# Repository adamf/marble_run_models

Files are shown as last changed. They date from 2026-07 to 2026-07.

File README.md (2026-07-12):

# marble_run_models



3D-printable models for translucent OEM marble runs (National Geographic
and similar). Parametric OpenSCAD source plus ready-to-slice STLs.

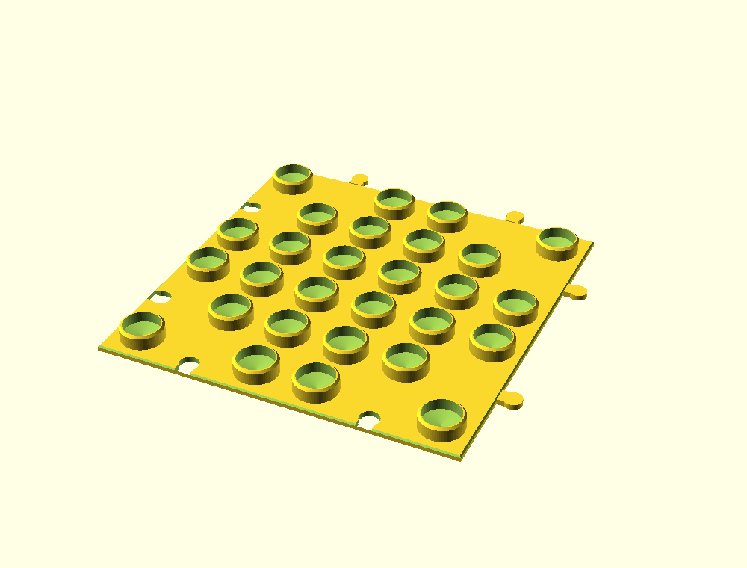
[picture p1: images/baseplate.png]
baseplate


## Base plate

A tileable base plate that gives marble-run stacks a stable footing. A
grid of hollow pegs plugs into the open (cup) end of the tubes the same
way the tubes' own male spigots plug into each other, so vertical columns
can't tip. Plates interlock edge-to-edge and the peg grid stays continuous
across the seams, so horizontal pieces can span two tiles.

| File | Description |
|---|---|
| `src/marble_run_baseplate.scad` | Parametric source (edit this) |
| `stl/marble_run_baseplate_5x5.stl` | 5×5 tile, 162×162×11mm |
| `stl/marble_run_calibration.stl` | Fit tester — **print this first** |

### Calibrate before printing tiles

Peg diameter depends on your exact tubes and can't be eyeballed. Print the
calibration strip (test pegs 24.0–27.0mm, labeled), push a real tube's cup
end onto each, and pick the snug one. Set `peg_od` to that value in the
`.scad`, re-export, then print tiles.

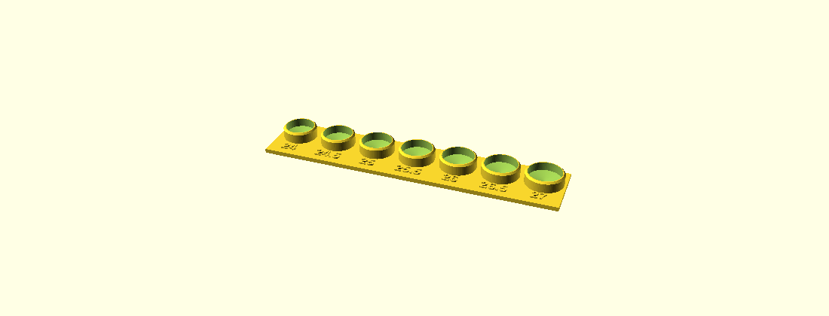
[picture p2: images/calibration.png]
calibration


### Print settings (Bambu)

Prints flat, pegs up, **no supports**.

- Material: PLA (easy) or PETG (tougher, better snap)
- Layer height: 0.2mm · Walls: 3–4 · Infill: 15–20%
- Brim: 5mm to prevent corner lift

### Key parameters

| Parameter | Purpose |
|---|---|
| `peg_od` | Peg diameter — the fit into your tubes (calibrate) |
| `pitch` | Grid spacing — match your set's module (default 30mm) |
| `grid_x`, `grid_y` | Pegs per tile |
| `peg_h` | Peg height / grip depth |
| `tab_tol` | Tightness of the plate-to-plate joint |

## Always-current models (CI)

A GitHub Actions workflow (`.github/workflows/build.yml`) re-renders the
STLs from the parametric source on every push that touches `src/`, then
commits the fresh models back into `stl/` and refreshes the preview images.
So the workflow is:

1. Edit a parameter in `src/marble_run_baseplate.scad` (e.g. `peg_od`
   after calibrating, or `grid_x`/`pitch`).
2. Commit and push.
3. A minute later, `stl/` holds the updated, ready-to-slice file — pulled
   straight into Bambu Studio, sliced in one click, sent to the printer.

The STLs are also attached to each run as downloadable **artifacts**
(Actions tab → latest run → *print-ready-stls*).

Run the same render locally any time with `./build.sh` (needs OpenSCAD).

> Note: replace `USERNAME` in the badge URL above with your GitHub handle.

## License

MIT — see [LICENSE](LICENSE). (Swap for CC-BY or remove if you'd rather.)

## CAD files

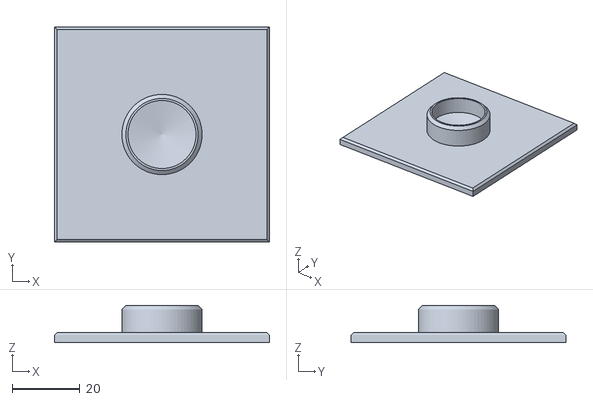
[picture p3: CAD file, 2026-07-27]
stl/marble_run_single_peg.stl
63.5 x 63.5 x 11.0

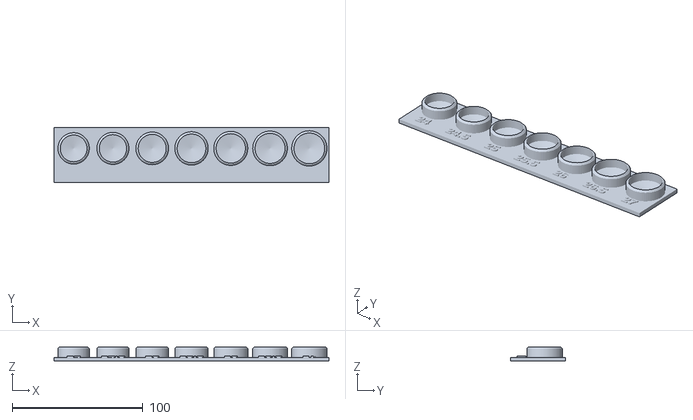
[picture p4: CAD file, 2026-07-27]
stl/marble_run_calibration.stl
210.0 x 42.0 x 11.0

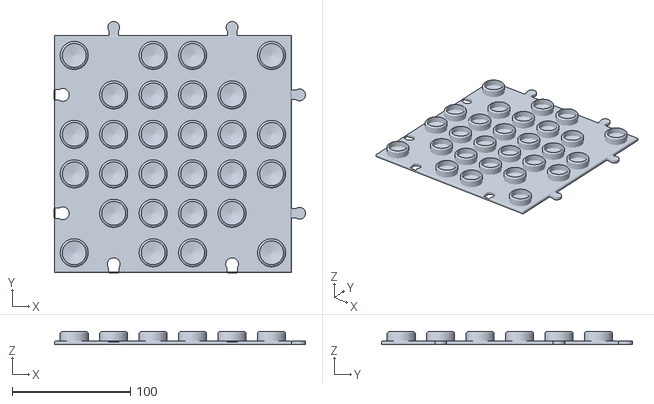
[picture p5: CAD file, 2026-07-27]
stl/marble_run_baseplate_6x6.stl
212.0 x 212.0 x 11.0

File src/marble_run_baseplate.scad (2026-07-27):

// =====================================================================
//  Marble-Run Base Plate  -  parametric, tileable, print-in-place
//  For National Geographic (and most translucent OEM) marble runs
//  Author: generated for Adam
//
//  HOW IT WORKS
//  ------------
//  A flat plate carries a grid of hollow pegs. Each peg is sized to
//  plug INTO the female (open) end of a marble-run tube, the same way
//  the tubes' own male spigots plug into each other. Stand a tube on a
//  peg and it can't tip. Pegs sit on a square grid whose pitch you set
//  to your set's module length, so horizontal pieces span whole grid
//  units. Plates interlock with jigsaw tabs so you can tile a big field.
//
//  >>> YOU MUST CALIBRATE peg_od TO YOUR TUBES <<<
//  Print marble_run_calibration.stl first (PART="calibration"),
//  push a real tube onto each test peg, pick the snuggest, and set
//  peg_od to that number below. Then print the tiles.
// =====================================================================

PART = "tile";          // "tile", "calibration", or "single"

// ---------- GRID ----------
grid_x       = 6;       // pegs across
grid_y       = 6;       // pegs deep
span_mod     = 100;     // measured span/ramp foot-to-foot center-to-center
subs_per_span = 3;      // pegs the span spans (feet land on pegs
                        //     subs_per_span cells apart, with subs-1
                        //     intermediate support pegs sitting under the
                        //     span body). Denser = more column-support
                        //     pegs. Limit: pitch > peg_od (no overlap), so
                        //     subs_per_span < span_mod/peg_od ~= 4.2, i.e.
                        //     max 4 (but 4 leaves only ~1mm gap between
                        //     peg edges - risky to print). 3 is comfy.
pitch        = span_mod / subs_per_span;
                        // == 100/3 = 33.333mm. Grid continuity (pegs at
                        // pitch/2 from every edge) means a span also fits
                        // across a seam: A's last peg sits pitch/2 from
                        // the seam, then N-1 intermediate pegs on B, then
                        // B's N-th peg lands 100mm from A_last.

// ---------- PEG (the bit that plugs into a tube) ----------
peg_od       = 23.7;    // <-- CALIBRATED for user's Bambu + Nat-Geo tubes:
                        //     firm/snug fit. Progression: 25.4 -> 24.0 ->
                        //     23.9 -> 23.8 -> 23.7 as the user dialed in a
                        //     slightly easier on/off.
                        //     Outer dia of peg = female-socket ID of your
                        //     tubes minus a snug clearance.
peg_wall     = 1.8;     // peg wall thickness (hollow peg flexes = grip)
peg_h        = 8;       // how far the peg sticks up
peg_top_cham = 1.2;     // lead-in chamfer at peg tip (easier to seat)
peg_flare_h  = 2.0;     // internal flare at the peg's base: the bore
                        //     tapers from fully closed at the underside up
                        //     to the nominal bore radius over this height,
                        //     then continues straight to the top. The wall
                        //     is thick at the base for strength, and the
                        //     outer stays flat at peg_od so tube feet seat
                        //     flush against the plate (no external lip).

// ---------- BASE ----------
base_th      = 3.0;     // plate thickness
edge_cham    = 0.8;     // top-perimeter chamfer (nicer to handle)

// ---------- TILE-TO-TILE CONNECTORS (jigsaw) ----------
connectors_on   = true;
conn_cells      = [1, 4];  // which edge grid-cells become connectors
                           // (0-indexed). Those edge pegs are omitted to
                           // make room. [1,4] = 2 per edge on a 6-wide,
                           // symmetric and clear of the corners.
tab_reach   = 12;       // how far a tab sticks out
tab_neck_w  = 8;        // neck width
tab_head_d  = 10;       // head diameter (>neck = it catches). Kept only
                        //   modestly larger so tiles PRESS together with
                        //   PLA's natural edge flex instead of needing a
                        //   hard snap that could crack.
tab_tol     = 0.40;     // clearance in the socket. Bigger = looser.
                        //   Too stiff to press together? raise to 0.6.
                        //   Falls apart? lower to 0.25.

// ---------- quality ----------
$fn = 64;

// ================= derived =================
plate_w = grid_x * pitch;   // physical footprint = N*pitch  -> grid stays
plate_d = grid_y * pitch;   // continuous across tiles (border = pitch/2)
eps = 0.01;

// ================= modules =================

// one hollow peg centered at origin, base sitting on z=0
module peg() {
    r  = peg_od/2;
    ri = r - peg_wall;
    // straight outer shaft (no external skirt) + tapered internal bore.
    difference() {
        union() {
            cylinder(h=peg_h - peg_top_cham, r=r);
            translate([0,0,peg_h - peg_top_cham])
                cylinder(h=peg_top_cham, r1=r, r2=r-peg_top_cham);
        }
        // bore: closed at the underside (r=0) tapering out to ri over
        // peg_flare_h -> reinforced base without any outer bump; then
        // straight ri up through and out the top.
        union() {
            cylinder(h=peg_flare_h, r1=0, r2=ri);
            translate([0,0,peg_flare_h - eps])
                cylinder(h=peg_h+1, r=ri);
        }
    }
}

// 2D jigsaw profile, protruding along +Y from the seam line y=0
module jigsaw2d(reach, neck_w, head_d, grow=0) {
    hr = head_d/2 + grow;
    nw = neck_w + 2*grow;
    hull_y = reach - head_d/2;      // head center
    union() {
        // neck
        translate([0,(hull_y)/2])
            square([nw, hull_y + eps], center=true);
        // head
        translate([0, hull_y]) circle(r=hr);
    }
}

// a connector TAB (adds material), seam at y=0, sticks toward +Y
module tab3d() {
    linear_extrude(base_th) jigsaw2d(tab_reach, tab_neck_w, tab_head_d, 0);
}
// a connector SOCKET (removes material), seam at y=0, opens toward -Y
module socket3d() {
    // mirror of the tab, grown by tolerance, pushed a hair past the seam
    translate([0,eps,-eps])
        linear_extrude(base_th+2*eps)
            jigsaw2d(tab_reach, tab_neck_w, tab_head_d, tab_tol);
}

// is edge-cell index k one of the connector cells?
function is_conn(k) = connectors_on &&
    len(search(k, conn_cells)) > 0;

// ================= the tile =================
module tile() {
    difference() {
        union() {
            // ---- base slab with chamfered top perimeter ----
            difference() {
                cube([plate_w, plate_d, base_th]);
                // chamfer top edges
                if (edge_cham > 0)
                    perimeter_chamfer();
            }

            // ---- pegs (skip edge cells that host a connector) ----
            for (i=[0:grid_x-1], j=[0:grid_y-1]) {
                on_left   = (i==0);
                on_right  = (i==grid_x-1);
                on_front  = (j==0);
                on_back   = (j==grid_y-1);
                // omit a peg only if it sits on an edge AND that edge cell
                // (indexed along the edge) is a connector cell
                skip =
                    (on_left   && is_conn(j)) ||
                    (on_right  && is_conn(j)) ||
                    (on_front  && is_conn(i)) ||
                    (on_back   && is_conn(i));
                if (!skip)
                    translate([(i+0.5)*pitch, (j+0.5)*pitch, base_th - eps])
                        peg();
            }

            // ---- connector TABS on +X and +Y edges ----
            if (connectors_on) {
                for (j=[0:grid_y-1]) if (is_conn(j))   // +X (right) edge
                    translate([plate_w, (j+0.5)*pitch, 0])
                        rotate([0,0,-90]) tab3d();
                for (i=[0:grid_x-1]) if (is_conn(i))   // +Y (back) edge
                    translate([(i+0.5)*pitch, plate_d, 0])
                        tab3d();
            }
        }

        // ---- connector SOCKETS on -X and -Y edges ----
        // socket3d() opens toward +Y from y=0, so it must be aimed INTO the
        // plate. On -Y edge that means no rotation; on -X edge rotate -90
        // around Z so +Y -> +X. (Bug: +90/+180 aimed sockets outward and
        // left the edges with tabs but no pockets.)
        if (connectors_on) {
            for (j=[0:grid_y-1]) if (is_conn(j))        // -X (left) edge
                translate([0, (j+0.5)*pitch, 0])
                    rotate([0,0,-90]) socket3d();
            for (i=[0:grid_x-1]) if (is_conn(i))        // -Y (front) edge
                translate([(i+0.5)*pitch, 0, 0])
                    socket3d();
        }
    }
}
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

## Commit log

2026-07-12 Add marble-run base plate: parametric OpenSCAD source, 5x5 tile + calibration STLs, renders, docs
    [marble_run_baseplate.scad, marble_run_baseplate_5x5.stl, marble_run_calibration.stl]
2026-07-12 Add CI: auto-render and commit print-ready STLs on push
    [marble_run_baseplate_5x5.stl, marble_run_calibration.stl]
2026-07-12 Remove stray build/ artifacts; ignore build/
    [marble_run_baseplate_5x5.stl, marble_run_calibration.stl]
2026-07-13 Fix connectors: carve female sockets into -X/-Y edges so tiles mate
    [marble_run_baseplate_5x5.stl, marble_run_calibration.stl]
2026-07-13 Land connector fix in src + set peg_od to calibrated 24.0
    The prior "Fix connectors" commit only touched STLs — src still aimed the
    -X/-Y sockets outward. Correct the rotations so the female pockets carve
    into the plate, and drop peg_od from the generic 25.4 to the value the
    user measured as a firm fit on their Bambu (24.0). Also track CLAUDE.md
    so future sessions inherit the design invariants and calibration notes.
    [marble_run_baseplate.scad]
2026-07-13 ci: refresh print-ready models [skip ci]
    [marble_run_baseplate_5x5.stl, marble_run_calibration.stl]
2026-07-14 Shrink peg OD to 23.9, add internal-only base flare, match span pitch
    - peg_od 24.0 -> 23.9 for a touch more give on/off.
    - Remove the external skirt lip so tube feet seat flush against the plate.
    Reinforcement stays as an INTERNAL flare: bore is closed (r=0) at the
    underside and tapers out to the nominal ri over peg_flare_h (2mm), then
    runs straight. Wall is thickest where the peg meets the plate.
    - pitch 30 -> 60 to match the user's span/ramp module, so each foot of a
    span piece lands on an adjacent peg (verified against a green Nat-Geo
    span). A 5x5 tile is now 300x300mm; drop grid_x/grid_y if that's too
    large for the print bed.
    - CLAUDE.md updated to reflect the new calibratio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
    [marble_run_baseplate.scad, marble_run_baseplate_5x5.stl, marble_run_calibration.stl]
2026-07-14 Denser 6x6 tile @ 30mm pitch; span still fits within & across tiles
    Halve the peg pitch (60 -> 30 mm) and grow the grid (5x5 -> 6x6). Result:
    tile shrinks from 300x300 -> 180x180 mm and peg count rises from 25 -> 36
    without breaking span placement:
    - Span foot-to-foot is ~60mm (2 * pitch), so both feet sit on pegs 2
    grid-cells apart on the same tile.
    - Grid continuity (pegs at pitch/2 from every edge) means the same 60mm
    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
    [marble_run_baseplate.scad, marble_run_baseplate_5x5.stl, marble_run_calibration.stl]
2026-07-14 Retune to measured 100mm span: pitch 50, grid 4x4, peg_od 23.8
    User measured the span piece's foot-to-foot center-to-center at 100mm
    (prior 60mm estimate from the photo was wrong). Reworked the tile so the
    span still fits within a tile and across a seam:
    - pitch 30 -> 50 (half the span module, so span feet land on pegs 2 apart).
    - grid 6x6 -> 4x4, giving a 200x200mm tile with 16 pegs.
    - Span across seam: A_last is 25mm from the seam, B_second is 75mm past
    it -> 100mm end-to-end. Also works via A_secondToLast + B_first (75+25).
    - Cannot shrink pitch further at this span length: would require pegs 3+
    apart and pitches tight enough to make peg/tube-foot clearance fail.
    Also:
    - peg_od 23.9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
    [marble_run_baseplate.scad, marble_run_baseplate_4x4.stl]
2026-07-14 Denser 6x6 tile @ pitch 100/3 for column-support: 36 pegs, 100mm span still fits
    Plate's primary job is holding up marble-run columns, so more pegs = more
    support. Kept the 200x200mm tile size but jumped from 16 to 36 pegs by
    setting pitch = span_mod / subs_per_span with subs_per_span = 3:
    - pitch = 100 / 3 = 33.333 mm (~9.5mm peg-edge gap - comfortable to print).
    - Span (100mm foot-to-foot) rests on pegs 3 grid-cells apart, with 2
    intermediate support pegs sitting under the span body (peg height 8mm
    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
    [marble_run_baseplate.scad, marble_run_baseplate_4x4.stl, marble_run_calibration.stl]
2026-07-15 Reduce peg_od by 0.1 to 23.7 for easier fit
    Continues the calibration progression (25.4 -> 24.0 -> 23.9 -> 23.8 -> 23.7)
    for a slightly easier on/off. Peg spacing unchanged (span_mod=100, pitch=100/3).
    Claude-Session: https://claude.ai/code/session_01DfcwWXTzoM3z23bBGNbySJ
    [marble_run_baseplate.scad]
2026-07-27 Add single-peg post model (2.5" square plate, 1 peg)
    New PART="single" variant: a 63.5mm square base with one centered peg
    reusing the calibrated peg() geometry. Handy for propping up a lone
    tube/column where a full 6x6 tile is overkill. Wired into build.sh.
    [marble_run_baseplate.scad, marble_run_single_peg.stl]
